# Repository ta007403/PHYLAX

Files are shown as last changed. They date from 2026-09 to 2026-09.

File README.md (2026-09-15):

# PHYLAX — Open-Source Bitcoin Hardware Wallet

**PHX-001 · Version 3 · Square Button**

PHYLAX (Greek *φύλαξ*, "guardian") is an open-source, Bitcoin-only hardware wallet built around a simple idea: no black-box chips, no wireless radios, no telemetry, and firmware you can read and verify yourself. This repository contains the KiCad hardware design files for the PHYLAX Version 3 board (square button variant).

🌐 Website: [phylaxwallet.com](https://phylaxwallet.com/)

> **Status:** In development — prototype targeted for Q4 2026. Hardware and firmware are subject to change.

---

## Why PHYLAX

- **Zero black-box chips** — no proprietary secure element; every component is one you can trace and verify.
- **Fully open firmware** — released under GPL v3.
- **Bitcoin-only** — no altcoins, no unnecessary attack surface.
- **No wireless radios, no telemetry** — the device only talks over USB-C, and only when you plug it in.
- **Built by the community** — the project is developed and audited in the open.

## What's in This Repository

This is a **KiCad 8 project** containing the schematic, PCB layout, 3D models, fabrication outputs, and supporting library parts for the PHYLAX board.

```
Phylax_Version_3 Square Button/
├── Phylax_Version_3.kicad_pro       # KiCad project file
├── Phylax_Version_3.kicad_sch       # Schematic
├── Phylax_Version_3.kicad_pcb       # PCB layout
├── 3D/                              # 3D models & case designs (.step, .stl, .FCStd, .scad)
├── Library/                         # Custom symbol, footprint, and 3D model libraries per part
├── Gerber/                          # Fabrication (Gerber/drill) outputs
├── PCB Outline/                     # Board outline drawings (DXF/PDF)
├── production/                      # BOM, position files, netlist, and production archives
├── Phylax_Version_3-backups/        # KiCad autosave/backup archives
├── fp-lib-table / sym-lib-table     # KiCad footprint & symbol library tables
└── Button Note.txt                  # Working design notes on component substitutions
```

### Key components

| Part | Role |
|---|---|
| STM32F205RET6 | Main microcontroller |
| SX1308 | Boost converter |
| MCP1703AT-3302E | 3.3V LDO regulator |
| USB4215-03-A | USB-C connector |
| SKHCBEA010 | Tactile push button |
| ABMM2-8.000MHZ-E2-T | Crystal oscillator |

*(See `production/bom.csv` for the full bill of materials.)*

## Getting Started

### Prerequisites

- [KiCad 8](https://www.kicad.org/download/) or later
- (Optional) [FreeCAD](https://www.freecad.org/) to view/edit the `.FCStd` case files
- (Optional) [OpenSCAD](https://openscad.org/) to view/edit the `.scad` case files

### Opening the project

1. Clone this repository:
   ```bash
   git clone https://github.com/ta007403/PHYLAX.git
   cd PHYLAX
   ```
2. Open `Phylax_Version_3.kicad_pro` in KiCad.
3. Schematic, PCB, and 3D viewer are all accessible from the KiCad project manager.

### Manufacturing

Fabrication-ready outputs (Gerbers, drill files, BOM, and pick-and-place data) are provided in the `Gerber/` and `production/` folders for sending directly to a PCB manufacturer/assembler.

## Contributing

PHYLAX is built in the open and welcomes community review and contributions — from schematic review to case design. Please open an issue or pull request with proposed changes. If you spot a design or safety issue, responsible disclosure is appreciated.

## License

Firmware and hardware design files are released under **GPL v3** unless otherwise noted. See the [PHYLAX manifesto](https://phylaxwallet.com/manifesto) and [specs](https://phylaxwallet.com/specs) for more on the project's philosophy and technical details.

## Links

- Website: [phylaxwallet.com](https://phylaxwallet.com/)
- Specifications: [phylaxwallet.com/specs](https://phylaxwallet.com/specs)
- Manifesto: [phylaxwallet.com/manifesto](https://phylaxwallet.com/manifesto)
- Journal / build updates: [phylaxwallet.com/journal](https://phylaxwallet.com/journal/)
- Facebook: [facebook.com/phylaxwallet](https://www.facebook.com/phylaxwallet)

---

*Not your keys, not your coins — PHYLAX gives you the keys.*

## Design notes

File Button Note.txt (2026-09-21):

SKHCBEA010 = 1.27 N
SKHCBGA010  =2.55 N

Switch Caps
SK2AA00090 = Black
SK2AA00080 = Ivory
SK2AA00060 = Red
SK2AA00070 = Blue

RC0603FR-07910KL แทด 910k 1% R
RC0603FR-0710KL แทน 10K 1% R

C2827688 ทดแทน PRTR5V0U2X

รอบหน้าต้องแก้
I think the real issue is not the capacitors.
Your design comments indicate:

22 µF / 25 V 1206
4.7 µF / 25 V 0805
10 µF / 16 V 0805

But the PCB footprint is 0603.

------------------------------------------------
LCSC Part #
100nFX7R0603 = C14663
100nFX7R25V0603 = C14663
R1 R2 = C852856
R3 = C313710
R4 = C2686485
R5 = C22356470
R7 = C2909316
R9 = C137672
R10 = C2974031
R11 = C98220

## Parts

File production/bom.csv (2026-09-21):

Designator | Footprint | Quantity | Value | LCSC Part #
C1 | 0603 | 1 | 1nF 200V X7R 0603
C10, C11, C12, C17, C20, C22, C4, C8, C9 | 0603 | 9 | 100nF X7R 25V 0603 | C14663
C13, C14 | 0603 | 2 | 2.2uF X7R 0603
C15 | 0805 | 1 | 4.7uF X7R 25V 0805
C16, C5, C6 | 0603 | 3 | 1uF X7R 0603
C2, C3 | 0402 | 2 | 22pF X7R 0402
C21 | 1206 | 1 | 22uF X5R 25V 1206
C23 | 0805 | 1 | 10uF X7R 16V 0805
C7 | 0603 | 1 | 4.7uF X7R 0603
D1 | PRTR5V0U2X | 1 | PRTR5V0U2X,215 | C12333
D2 | SOD2513X117N | 1 | BAT60JFILM | C133103
D3 | SOD-123_L2.7-W1.6-LS3.7-RD | 1 | 1N5819HW-7-F | C82544
F2 | FUSC4632X85N | 1 | MF-MSMF050-2 | C17313
IC1 | SOT95P255X145-3N | 1 | MCP1703AT-3302E_CB | C144183
IC2 | QFP50P1200X1200X160-64N | 1 | STM32F205RET6 | C66278
J2 | FH19C24S05SH10 | 1 | FH19C-24S-0.5SH_10_ | C6555469
L2 | IND-SMD_L4.0-W4.0_XAL4040 | 1 | XAL4040-103MEC | C5144883
R1, R2 | 0402 | 2 | 5.1k +-1% 0402 | C852856
R10 | 0603 | 1 | 191k +-1% 0603 | C2974031
R11 | 0603 | 1 | 10k +-1% 0603 | C98220
R3 | 0603 | 1 | 22R +-1% 0603 | C313710
R4 | 0402 | 1 | 22R +-1% 0402 | C2686485
R5 | 0603 | 1 | 1M +-1% 0603 | C22356470
R7 | 0402 | 1 | 12k +-1% 0402 | C2909316
R9 | 0603 | 1 | 910k +-1% 0603 | C23263
S1, S3 | SKHCBGA010 | 2 | SKHCBGA010
U1 | SOT-23-6_L2.9-W1.6-P0.95-LS2.8-BL | 1 | SX1308 | C78162
USB1 | USB-C-SMD_GT-USB-7010B | 1 | USB4215-03-A | C37616412
Y1 | ABMM2 | 1 | ABMM2-8.000MHZ-E2-T | C431529

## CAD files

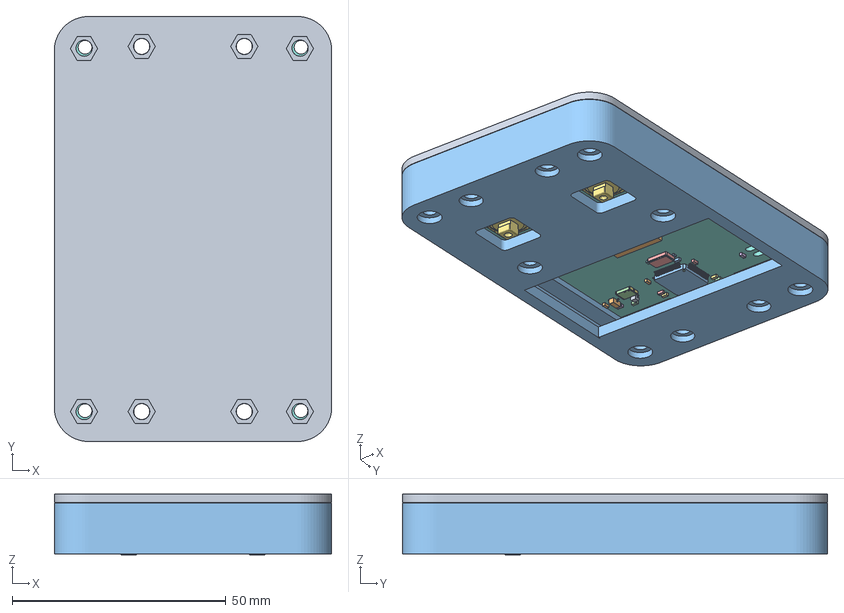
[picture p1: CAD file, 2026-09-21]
3D/Version 3.3/Assembly.FCStd
64.9 x 99.4 x 14.3 mm
C_0603_1608Metric
C_0603_1608Metric001
SOD-123_L2.7-W1.6-H1.4-LS3.7
SDSDS
SDSDS001
pIN eXTEND
pIN eXTEND001
gOLD
gOLD001
gOLD002
gOLD003
Bourns Logo-LAPTOP-NQA1DCQ3
Bourns Logo-LAPTOP-NQA1DCQ001
Bourns Logo-LAPTOP-NQA1DCQ002
Bourns Logo-LAPTOP-NQA1DCQ003
Bourns Logo-LAPTOP-NQA1DCQ004
Bourns Logo-LAPTOP-NQA1DCQ005
C_0402_1005Metric
C_0603_1608Metric002
C_0603_1608Metric003
C_0603_1608Metric004
SKHCBEA010
C_0603_1608Metric005
R_0603_1608Metric
Pins
Pins001
Pins002
Pins003
Pins004
Pins005
Pins006
Pins007
Pins008
Pins009
Pins010
Pins011
Pins012
Pins013
Pins014
Pins015
Pins016
Pins017
Pins018
Pins019
Pins020
Pins021
Pins022
Pins023
Pins024
Pins025
ABMM2-8.000MHZ-E2-T
C_0603_1608Metric006
C_0603_1608Metric007
SOT-23-6_L2.9-W1.6-H1.5-LS2.8-P0.95
SOT-23-6_L2.9-W1.6-H1.5-LS2.8-P0.001
SOT-23-6_L2.9-W1.6-H1.5-LS2.8-P0.002
SOT-23-6_L2.9-W1.6-H1.5-LS2.8-P0.003
SOT-23-6_L2.9-W1.6-H1.5-LS2.8-P0.004
SOT-23-6_L2.9-W1.6-H1.5-LS2.8-P0.005
SOT-23-6_L2.9-W1.6-H1.5-LS2.8-P0.006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

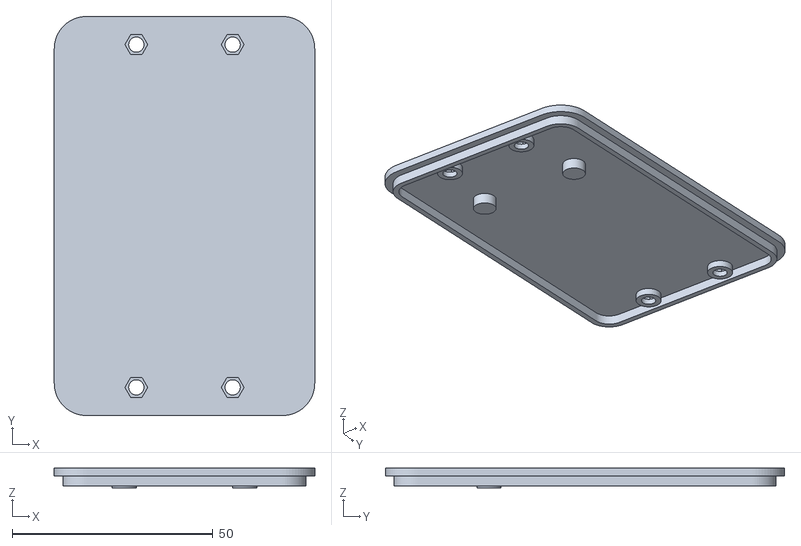
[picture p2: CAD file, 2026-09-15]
3D/Back Tar Version v3.stl
64.9 x 99.4 x 4.90

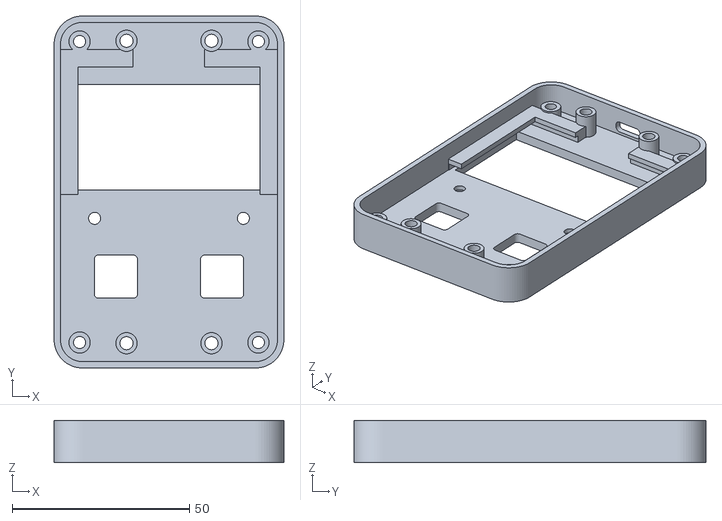
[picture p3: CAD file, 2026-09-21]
3D/Version 3.3/Front v3-3.stl
64.9 x 99.4 x 11.9

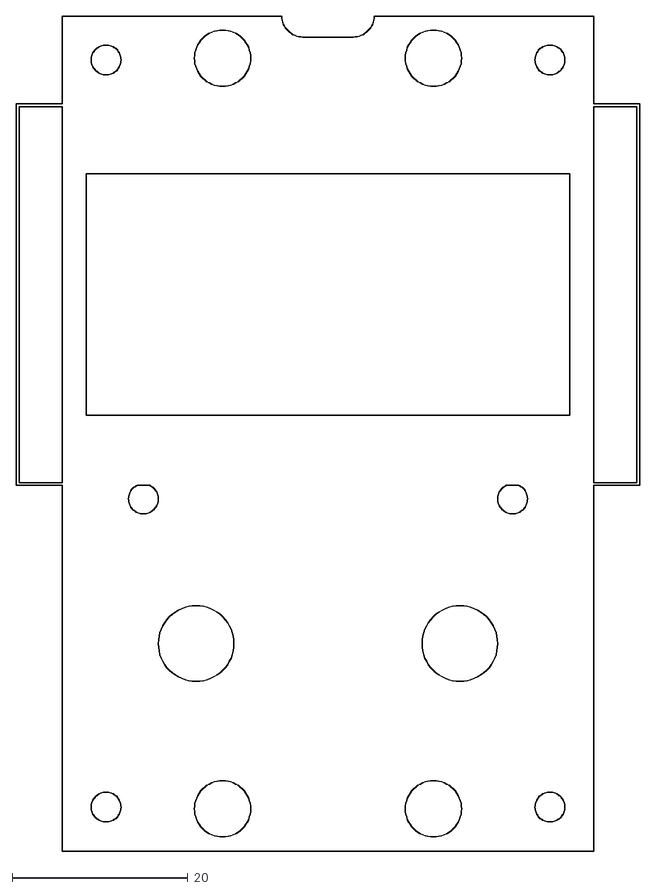
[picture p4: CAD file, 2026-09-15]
PCB Outline/PCB_Outline_Version3.dxf
70.9 x 95.0

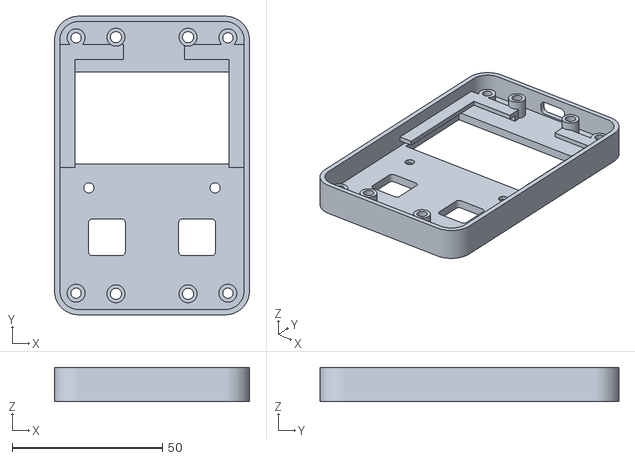
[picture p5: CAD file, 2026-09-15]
3D/Front Tar Version v3.stl
64.9 x 99.4 x 11.4

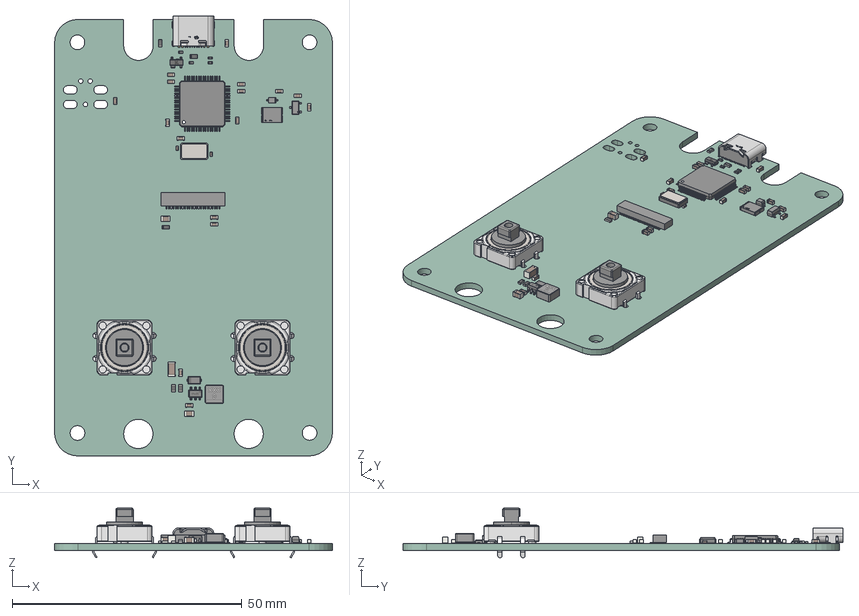
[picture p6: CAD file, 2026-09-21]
3D/Version 3.3/Phylax_Version_3-2.step
60.5 x 95.7 x 10.8 mm
C_0603_1608Metric x 16
SOD-123_L2.7-W1.6-H1.4-LS3.7
SDSDS
pIN eXTEND
gOLD
Bourns Logo-LAPTOP-NQA1DCQ3
C_0402_1005Metric x 2
SKHCBEA010 x 2
R_0603_1608Metric x 5
Pins
ABMM2-8.000MHZ-E2-T
SOT-23-6_L2.9-W1.6-H1.5-LS2.8-P0.95
R_0402_1005Metric x 4
C_1206_3216Metric
PinsArrayL
FilletPinR x 2
C_0805_2012Metric x 2
USB-C-SMD_GT-USB-7010B
FilletPinL
IND-SMD_L4.0-W4.0_XAL4040
STM32F205RET6
SOT143B lower body
SOT143B small Lead x 3
SOT143B Large lead
SOT143B Upper body
Phylax_Version_3_PCB

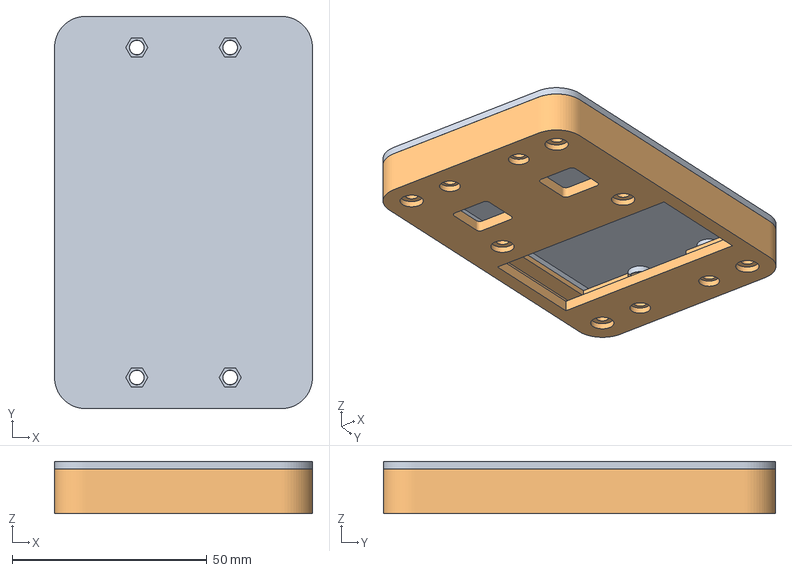
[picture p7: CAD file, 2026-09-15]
3D/Phylax 3D Test v3.FCStd
66.3 x 100.8 x 13.4 mm
Back Tar Version v3
Front Tar Version v3
Front Tar Version v004

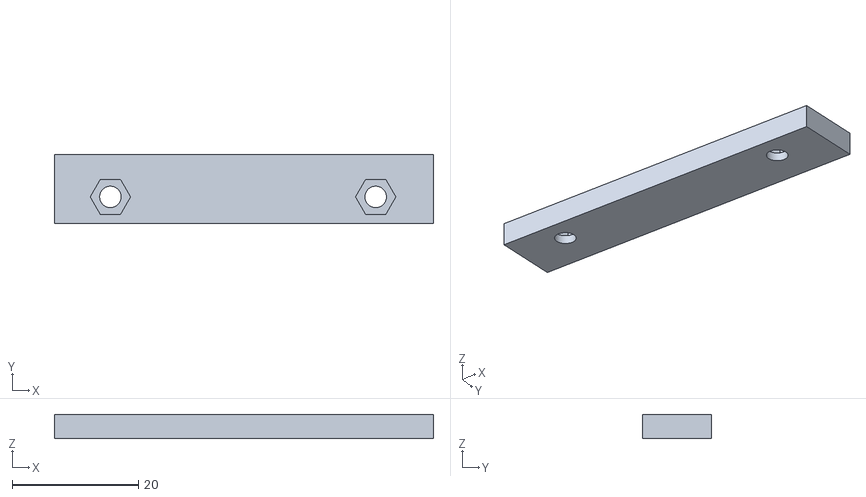
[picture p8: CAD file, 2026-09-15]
3D/Version 3.3/Display Lock v3-2.stl
60.0 x 11.0 x 3.80

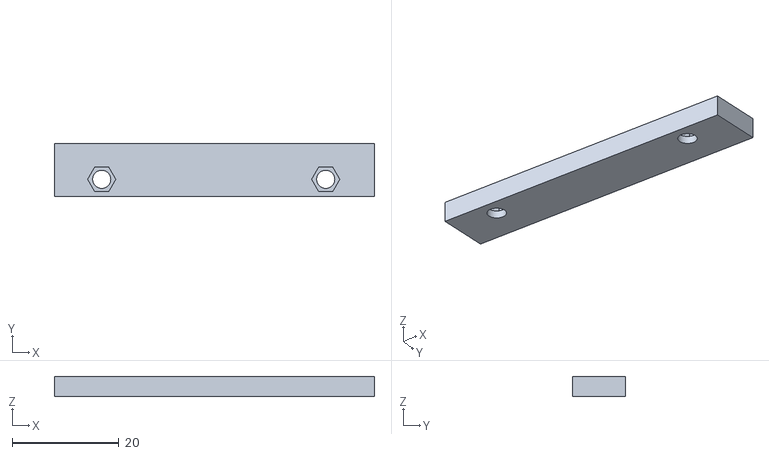
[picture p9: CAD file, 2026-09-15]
3D/Display Lock Tar Version v3.stl
60.0 x 10.0 x 3.80

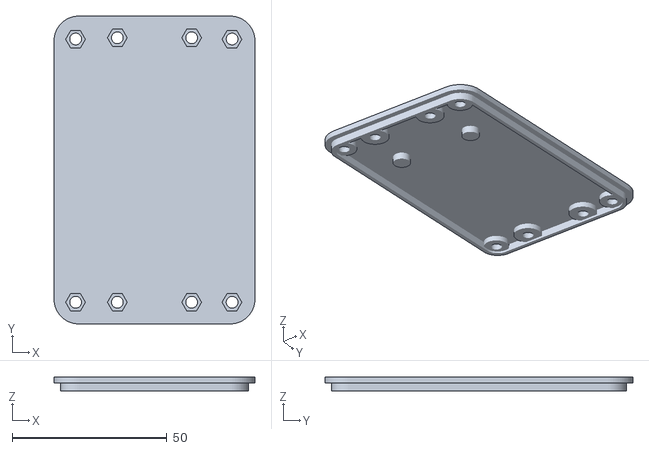
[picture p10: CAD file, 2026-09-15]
3D/Version 3.3/Back v3-3.stl
64.9 x 99.4 x 4.50

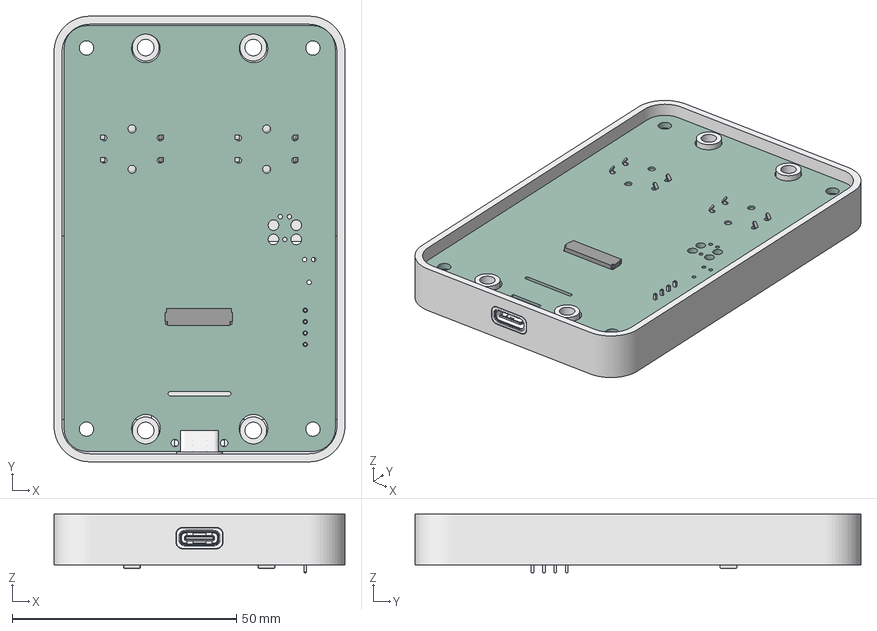
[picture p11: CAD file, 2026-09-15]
3D/PCB + Front.FCStd
64.9 x 99.4 x 13.1 mm
C_0603_1608Metric
C_0603_1608Metric001
C_0402_1005Metric
C_0603_1608Metric002
C_0603_1608Metric003
C_0603_1608Metric004
SKHCBEA010
C_0603_1608Metric005
R_0603_1608Metric
ABMM2-8.000MHZ-E2-T
C_0603_1608Metric006
C_0603_1608Metric007
R_0603_1608Metric001
10178589-00011LF
R_0603_1608Metric002
R_0603_1608Metric003
PinsArrayL
PinsArrayL001
FilletPinR
term1
term2
C_0603_1608Metric008
C_0603_1608Metric009
R_0603_1608Metric004
C_0603_1608Metric010
R_0603_1608Metric005
R_0603_1608Metric006
FilletPinL
FilletPinR001
R_0603_1608Metric007
C_0603_1608Metric011
SKHCBEA011
C_0402_1005Metric001
C_0603_1608Metric012
C_0603_1608Metric013
C_0603_1608Metric014
R_0603_1608Metric008
STM32F205RET6
STM32F205RET007
STM32F205RET008
STM32F205RET009
STM32F205RET010
STM32F205RET011
STM32F205RET012
STM32F205RET013
STM32F205RET014
STM32F205RET015
STM32F205RET016
STM32F205RET017
STM32F205RET018
STM32F205RET019
STM32F205RET020
STM32F205RET021
STM32F205RET022
STM32F205RET023
STM32F205RET024
STM32F205RET025
STM32F205RET026
STM32F205RET027
STM32F205RET028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

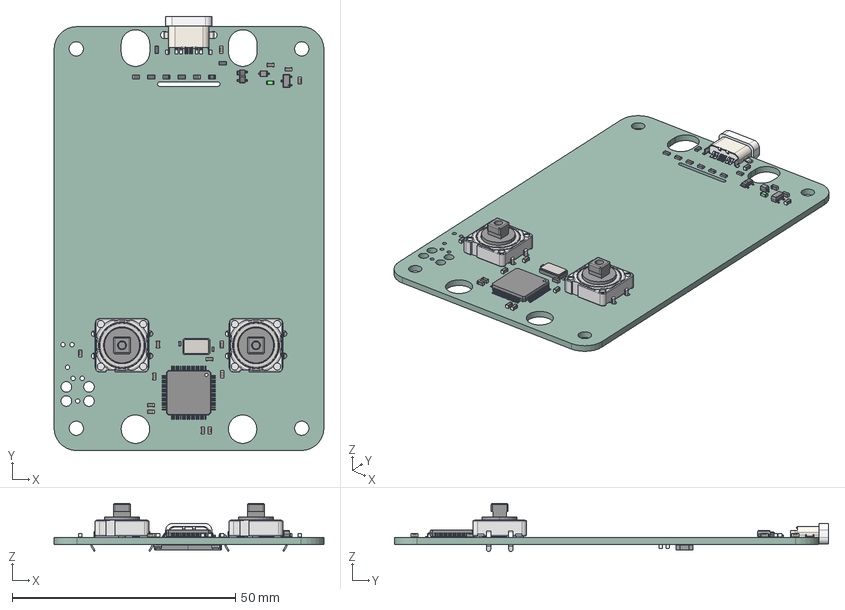
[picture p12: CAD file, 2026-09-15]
3D/Phylax_Version_3.step
60.5 x 97.3 x 10.8 mm
C_0603_1608Metric x 17
C_0402_1005Metric x 2
SKHCBEA010 x 2
R_0603_1608Metric x 9
ABMM2-8.000MHZ-E2-T
10178589-00011LF
PinsArrayL
FilletPinR x 2
term1
term2
FilletPinL
STM32F205RET6
SOT143B lower body
SOT143B small Lead x 3
SOT143B Large lead
SOT143B Upper body
Pins
Phylax_Version_3_PCB

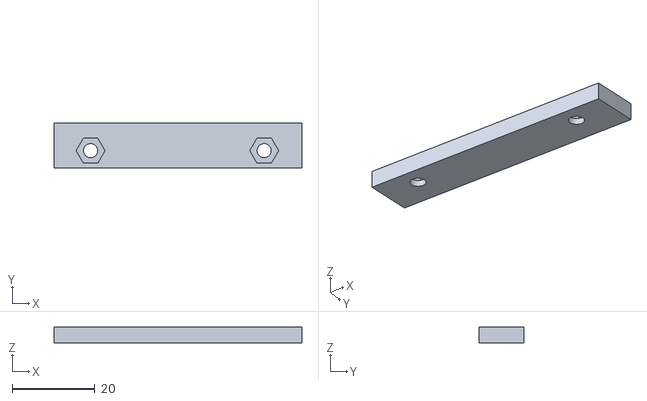
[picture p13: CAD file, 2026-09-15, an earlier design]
3D/Version 3.1/Display Lock v3-1.stl
60.0 x 11.0 x 3.80

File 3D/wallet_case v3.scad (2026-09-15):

// ============================================================
// HARDWARE WALLET CASE — Parametric OpenSCAD
// 2.42" SSD1309 OLED + 2x E-Switch TL1105YF160Q tact switches + USB-C
// PCB: 75 x 120 x 1.6mm
// ============================================================
//
// HOW TO USE THIS FILE
// ---------------------------------------------------------------
// Open the CUSTOMIZER panel: Window menu > Customizer (or the icon that
// looks like a slider/wrench in the toolbar). You'll see grouped controls:
//   - "View / Render Mode"     <- pick which part to look at / export
//   - "PCB", "Display", "Buttons", "USB-C Connector", "PCB Mounting Screws"
//   - "Case Shell", "Screw Bosses", "Front Shell Lip"
//
// To switch parts: open "View / Render Mode" and change the render_mode
// dropdown to back_shell / front_shell / button_cap / assembly.
//
// To print: pick a part in render_mode (NOT "assembly", that's preview-only),
// then File > Export > Export as STL. Repeat for each of the 3 parts
// (back_shell, front_shell, button_cap -- button_cap exports both caps
// laid out side by side in one file).
//
// Any value you change in the Customizer updates the model live. If you'd
// rather edit numbers directly in code, the same variables are declared in
// SECTION 1 / 1b below (search for the variable name) -- Customizer and
// direct code editing both work on the same values.
//
// PRINTING NOTES
// ---------------------------------------------------------------
// - Two shells (back_shell, front_shell) + two button_cap copies = 4 prints total.
// - Tolerances below are tuned for FDM with a 0.4mm nozzle. If you switch
//   to resin/SLA, look for "Front Shell Lip" group and tighten lip_clearance.
// - Back shell: print with the open face UP (no supports needed for the
//   bosses, since they're vertical cylinders rising from a flat floor).
// - Front shell: print with the BUTTON/DISPLAY face DOWN on the bed, since
//   the registration lip on the back is just a thin wall (prints fine
//   either way, but face-down avoids any visible seam on the visible side).
// - Button caps: print either orientation; they're small and simple.
//
// ============================================================

// Render quality
$fn = 64;

// I have modify this section
hex_round_head_m3_high = 1.65;
hide_m3_head = 4 - hex_round_head_m3_high;

/* [View / Render Mode] */
// Which part to show. Pick one, then File > Export > STL to print it.
render_mode = "assembly"; // [assembly:Assembly (preview only), back_shell:Back Shell (print 1x), front_shell:Front Shell (print 1x), button_cap:Button Caps (print 2x), display_lock:Display Lock (print 1x),front_and_lock:Front Shell + Display Lock, pcb_outline:PCB Outline (export as DXF for KiCad), none:Nothing]

/* [PCB] */
pcb_length   = 95;   // [60:200] mm, long axis (Y)
pcb_width    = 60.5;    // [40:150] mm, short axis (X)
pcb_thick    = 1.6;   // [0.8:0.1:3.2] mm

/* [Display - 2.42" SSD1309] */
disp_mod_w     = 70.9;   // mm, module long edge (runs along PCB width/X)
disp_mod_h     = 43.4;   // mm, module short edge (runs along PCB length/Y)
disp_active_w  = 55.01;  // mm, active viewing area width
disp_active_h  = 27.49;  // mm, active viewing area height
disp_pcb_thick = 1.2;    // mm, OLED module PCB thickness (assumption, thin FR4)
disp_glass_standoff = 0.5; // mm, assumption: glass sits slightly proud of module PCB
disp_margin_top = 10;     // [0:20] mm, gap from top edge of PCB to top edge of display module
disp_window_margin = 1.5; // [0.5:0.1:4] mm, extra margin around active area for the front cutout

/* [Buttons - Same Sky TS15-1212 Series] */
btn_body        = 12.0;   // mm, switch body (12x12mm per TS15 datasheet)
btn_plunger_d   = 7.0;    // mm, round actuator diameter (per TS15 mechanical drawing)
btn_plunger_h   = 4.8;   // [5:0.5:15] mm, actuator height above PCB -- set to match
                           // your ordered variant: 100=10mm, 150=15mm, 200=20mm (wrong series -- TS15 max is 15mm)
btn_spacing     = 30;     // [15:80] mm, center-to-center distance between the two buttons
btn_offset_below_display = 18; // [5:50] mm, gap from bottom of display to button row
btn_travel_above_case = 1.8; // [0.5:0.1:4] mm, how far the button DOME pokes above the front
                              // face -- this is what controls "how proud/clicky" the button
                              // looks and feels. Independent of plunger height: the shaft
                              // length to reach the plunger is calculated automatically.

/* [USB-C Connector] */
// Pick your connector type — all dimensions auto-adjust.
usbc_type = "normal"; // [sink:Sink Type - Amphenol 10178589 (IPX5 waterproof), normal:Normal SMD USB-C (standard)]

// Clearance added around the oval cutout on ALL sides.
// 0.4mm = safe FDM starting point. Decrease if plug is loose, increase if too tight.
usbc_clearance = 0.0; // [0.1:0.05:1.0] mm

/* [FPC Display Connector - Molex 522072460] */
// 24-circuit, 1mm pitch, right-angle SMD, 2.70mm height
// Place this connector so the FPC ribbon exits toward the display module above it.
fpc_w           = 26.0;  // mm, connector body width (24 circuits × 1mm pitch + housing ends ~2mm)
fpc_d           = 5.5;   // mm, connector body depth (right-angle footprint)
fpc_h           = 2.7;   // mm, connector height above PCB (from datasheet: 2.70mm)
// Position: centered on X, placed in the top half of PCB near the display edge
fpc_offset_from_top = 8; // [2:30] mm, distance from top PCB edge to near edge of connector


/* [PCB Mounting Screws - M3 + Nut] */
// PCB now mounts to the FRONT shell (display side), not the back shell.
// Screw enters from the OUTSIDE of the front shell (visible head, countersunk),
// passes through the PCB, and threads into a hex nut trapped inside the front
// shell's cavity wall. This lets the PCB stay attached to the front shell when
// the case is opened -- keeping the display's short FPC cable untouched.
mount_inset      = 5;    // [5:20] mm, distance of each screw position from PCB edge.
                           // Must clear BOTH the rounded case corners AND the
                           // display window edges -- 17mm verified clear of both
                           // with margin (M3 boss is 5mm dia). If you change
                           // disp_window size, case_corner_r, or pcb_boss_od,
                           // re-check this.
mount_hole_d     = 3.4;   // [3.0:0.1:4.0] mm, PCB clearance hole for M3 screw shank
m3_screw_d       = 3.0;   // mm, M3 screw nominal diameter (reference only)
m3_clear_d       = 3.4;   // [3.2:0.1:4.0] mm, clearance hole through front shell wall + PCB
m3_head_d        = 6.0;   // [5.5:0.1:7.0] mm, M3 COUNTERSUNK (flat head) screw head
                           // diameter -- DIN 965/ISO 7046 spec, e.g. M3x8 has 6.0mm head.
                           // Use a countersunk screw (not cap/pan head) so it sits flush.
m3_head_h        = 1.7;   // [1.5:0.1:2.5] mm, M3 countersunk head height (DIN 965 spec) --
                           // much shallower than a cap/pan head, fits cleanly within
                           // front_panel_t without needing a backing pad.
m3_nut_af        = 5.5;   // [5.3:0.1:6.0] mm, M3 hex nut width across flats
m3_nut_h         = 2.4;   // [2.0:0.1:3.0] mm, M3 hex nut thickness
m3_nut_clearance = 0.2;   // [0.05:0.05:0.4] mm, extra clearance around nut so it slides into the trap

/* [Display Lock Screws - M3 + Nut] */
// Two small M3 screws below the display window, used to hold a separate
// printed retainer piece that clamps the display's BOTTOM edge once it has
// been slid into the 3-sided L-channel (top/left/right) molded into the
// front shell. Positions are tied to the display window, not hardcoded,
// so they follow disp_center_x/y automatically if the display moves.
disp_lock_inset_x  = 8;    // [2:20] mm, how far in from each window side-edge
disp_lock_offset_y = 8;    // [2:20] mm, gap below the window's bottom edge
disp_lock_boss_od  = 5.0;  // [3:0.5:8] mm, lock screw boss outer diameter
                            // (smaller than the main PCB bosses -- this only
                            // holds a thin retainer clip, not the whole PCB)

/* [Hidden] */
disp_center_x   = pcb_width/2;
disp_center_y   = pcb_length - disp_margin_top - disp_mod_h/2;
usbc_center_x = pcb_width/2;
btn_center_y    = disp_center_y - disp_mod_h/2 - btn_offset_below_display;
btn_center_x_L  = pcb_width/2 - btn_spacing/2;
btn_center_x_R  = pcb_width/2 + btn_spacing/2;

mount_positions = [
    [mount_inset, mount_inset],
    [pcb_width - mount_inset, mount_inset],
    [mount_inset, pcb_length - mount_inset],
    [pcb_width - mount_inset, pcb_length - mount_inset]
];
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

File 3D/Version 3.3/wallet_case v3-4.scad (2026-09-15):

// ============================================================
// HARDWARE WALLET CASE — Parametric OpenSCAD
// 2.42" SSD1309 OLED + 2x E-Switch TL1105YF160Q tact switches + USB-C
// PCB: 75 x 120 x 1.6mm
// ============================================================
//
// HOW TO USE THIS FILE
// ---------------------------------------------------------------
// Open the CUSTOMIZER panel: Window menu > Customizer (or the icon that
// looks like a slider/wrench in the toolbar). You'll see grouped controls:
//   - "View / Render Mode"     <- pick which part to look at / export
//   - "PCB", "Display", "Buttons", "USB-C Connector", "PCB Mounting Screws"
//   - "Case Shell", "Screw Bosses", "Front Shell Lip"
//
// To switch parts: open "View / Render Mode" and change the render_mode
// dropdown to back_shell / front_shell / button_cap / assembly.
//
// To print: pick a part in render_mode (NOT "assembly", that's preview-only),
// then File > Export > Export as STL. Repeat for each of the 3 parts
// (back_shell, front_shell, button_cap -- button_cap exports both caps
// laid out side by side in one file).
//
// Any value you change in the Customizer updates the model live. If you'd
// rather edit numbers directly in code, the same variables are declared in
// SECTION 1 / 1b below (search for the variable name) -- Customizer and
// direct code editing both work on the same values.
//
// PRINTING NOTES
// ---------------------------------------------------------------
// - Two shells (back_shell, front_shell) + two button_cap copies = 4 prints total.
// - Tolerances below are tuned for FDM with a 0.4mm nozzle. If you switch
//   to resin/SLA, look for "Front Shell Lip" group and tighten lip_clearance.
// - Back shell: print with the open face UP (no supports needed for the
//   bosses, since they're vertical cylinders rising from a flat floor).
// - Front shell: print with the BUTTON/DISPLAY face DOWN on the bed, since
//   the registration lip on the back is just a thin wall (prints fine
//   either way, but face-down avoids any visible seam on the visible side).
// - Button caps: print either orientation; they're small and simple.
//
// ============================================================

// Render quality
$fn = 64;

// I have modify this section
hex_round_head_m3_high = 1.65;
hide_m3_head = 4 - hex_round_head_m3_high;

/* [View / Render Mode] */
// Which part to show. Pick one, then File > Export > STL to print it.
render_mode = "assembly"; // [assembly:Assembly (preview only), back_shell:Back Shell (print 1x), front_shell:Front Shell (print 1x), button_cap:Button Caps (print 2x), display_lock:Display Lock (print 1x),front_and_lock:Front Shell + Display Lock, pcb_outline:PCB Outline (export as DXF for KiCad), none:Nothing]

/* [PCB] */
pcb_length   = 95;   // [60:200] mm, long axis (Y)
pcb_width    = 60.5;    // [40:150] mm, short axis (X)
pcb_thick    = 1.6;   // [0.8:0.1:3.2] mm

/* [Display - 2.42" SSD1309] */
disp_mod_w     = 70.9;   // mm, module long edge (runs along PCB width/X)
disp_mod_h     = 43.4;   // mm, module short edge (runs along PCB length/Y)
disp_active_w  = 55.01;  // mm, active viewing area width
disp_active_h  = 27.49;  // mm, active viewing area height
disp_pcb_thick = 1.2;    // mm, OLED module PCB thickness (assumption, thin FR4)
disp_glass_standoff = 0.5; // mm, assumption: glass sits slightly proud of module PCB
disp_margin_top = 10;     // [0:20] mm, gap from top edge of PCB to top edge of display module
disp_window_margin = 1.5; // [0.5:0.1:4] mm, extra margin around active area for the front cutout

/* [Buttons - Same Sky TS15-1212 Series] */
btn_body        = 12.0;   // mm, switch body (12x12mm per TS15 datasheet)
btn_plunger_d   = 7.0;    // mm, round actuator diameter (per TS15 mechanical drawing)
btn_plunger_h   = 4.8;   // [5:0.5:15] mm, actuator height above PCB -- set to match
                           // your ordered variant: 100=10mm, 150=15mm, 200=20mm (wrong series -- TS15 max is 15mm)
btn_spacing     = 30;     // [15:80] mm, center-to-center distance between the two buttons
btn_offset_below_display = 18; // [5:50] mm, gap from bottom of display to button row
btn_travel_above_case = 1.8; // [0.5:0.1:4] mm, how far the button DOME pokes above the front
                              // face -- this is what controls "how proud/clicky" the button
                              // looks and feels. Independent of plunger height: the shaft
                              // length to reach the plunger is calculated automatically.

/* [USB-C Connector] */
// Pick your connector type — all dimensions auto-adjust.
usbc_type = "normal"; // [sink:Sink Type - Amphenol 10178589 (IPX5 waterproof), normal:Normal SMD USB-C (standard)]

// Clearance added around the oval cutout on ALL sides.
// 0.4mm = safe FDM starting point. Decrease if plug is loose, increase if too tight.
usbc_clearance = 0.0; // [0.1:0.05:1.0] mm

/* [FPC Display Connector - Molex 522072460] */
// 24-circuit, 1mm pitch, right-angle SMD, 2.70mm height
// Place this connector so the FPC ribbon exits toward the display module above it.
fpc_w           = 26.0;  // mm, connector body width (24 circuits × 1mm pitch + housing ends ~2mm)
fpc_d           = 5.5;   // mm, connector body depth (right-angle footprint)
fpc_h           = 2.7;   // mm, connector height above PCB (from datasheet: 2.70mm)
// Position: centered on X, placed in the top half of PCB near the display edge
fpc_offset_from_top = 8; // [2:30] mm, distance from top PCB edge to near edge of connector


/* [PCB Mounting Screws - M3 + Nut] */
// PCB now mounts to the FRONT shell (display side), not the back shell.
// Screw enters from the OUTSIDE of the front shell (visible head, countersunk),
// passes through the PCB, and threads into a hex nut trapped inside the front
// shell's cavity wall. This lets the PCB stay attached to the front shell when
// the case is opened -- keeping the display's short FPC cable untouched.
mount_inset      = 5;    // [5:20] mm, distance of each screw position from PCB edge.
                           // Must clear BOTH the rounded case corners AND the
                           // display window edges -- 17mm verified clear of both
                           // with margin (M3 boss is 5mm dia). If you change
                           // disp_window size, case_corner_r, or pcb_boss_od,
                           // re-check this.
mount_hole_d     = 3.4;   // [3.0:0.1:4.0] mm, PCB clearance hole for M3 screw shank
m3_screw_d       = 3.0;   // mm, M3 screw nominal diameter (reference only)
m3_clear_d       = 3.4;   // [3.2:0.1:4.0] mm, clearance hole through front shell wall + PCB

// This one is for outer lock at 4 corner by Tar
m3_head_d        = 5.8;   // [5.5:0.1:7.0] mm, M3 COUNTERSUNK (flat head) screw head
                           // diameter -- DIN 965/ISO 7046 spec, e.g. M3x8 has 6.0mm head.
                           // Use a countersunk screw (not cap/pan head) so it sits flush.
m3_head_h        = 1.7;   // [1.5:0.1:2.5] mm, M3 countersunk head height (DIN 965 spec) --
                           // much shallower than a cap/pan head, fits cleanly within
                           // front_panel_t without needing a backing pad.
m3_nut_af        = 5.5;   // [5.3:0.1:6.0] mm, M3 hex nut width across flats
m3_nut_h         = 2.4;   // [2.0:0.1:3.0] mm, M3 hex nut thickness
m3_nut_clearance = 0.2;   // [0.05:0.05:0.4] mm, extra clearance around nut so it slides into the trap

/* [Display Lock Screws - M3 + Nut] */
// Two small M3 screws below the display window, used to hold a separate
// printed retainer piece that clamps the display's BOTTOM edge once it has
// been slid into the 3-sided L-channel (top/left/right) molded into the
// front shell. Positions are tied to the display window, not hardcoded,
// so they follow disp_center_x/y automatically if the display moves.
disp_lock_inset_x  = 8;    // [2:20] mm, how far in from each window side-edge
disp_lock_offset_y = 8;    // [2:20] mm, gap below the window's bottom edge
disp_lock_boss_od  = 5.0;  // [3:0.5:8] mm, lock screw boss outer diameter
                            // (smaller than the main PCB bosses -- this only
                            // holds a thin retainer clip, not the whole PCB)

/* [Hidden] */
disp_center_x   = pcb_width/2;
disp_center_y   = pcb_length - disp_margin_top - disp_mod_h/2;
usbc_center_x = pcb_width/2;
btn_center_y    = disp_center_y - disp_mod_h/2 - btn_offset_below_display;
btn_center_x_L  = pcb_width/2 - btn_spacing/2;
btn_center_x_R  = pcb_width/2 + btn_spacing/2;

mount_positions = [
    [mount_inset, mount_inset],
    [pcb_width - mount_inset, mount_inset],
    [mount_inset, pcb_length - mount_inset],
    [pcb_width - mount_inset, pcb_length - mount_inset]
];
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

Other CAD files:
3D/Compose.FCStd
3D/Version 3.1/Assembly.FCStd
3D/Version 3.2/Assembly.FCStd
3D/Version 3.2/Phylax_Version_3-1.step
3D/Version 3.1/Front v3-1.stl
3D/Version 3.2/wallet_case v3-3.scad
3D/Version 3.1/Back v3-1.stl
3D/Version 3.1/Back v3-2.stl
3D/Version 3.1/Phylax_Version_3-1.step
3D/Version 3.2/Back v3-1.stl
3D/Version 3.2/Back v3-2.stl
3D/Version 3.2/Front v3-1.stl
3D/Version 3.2/Front v3-2.stl

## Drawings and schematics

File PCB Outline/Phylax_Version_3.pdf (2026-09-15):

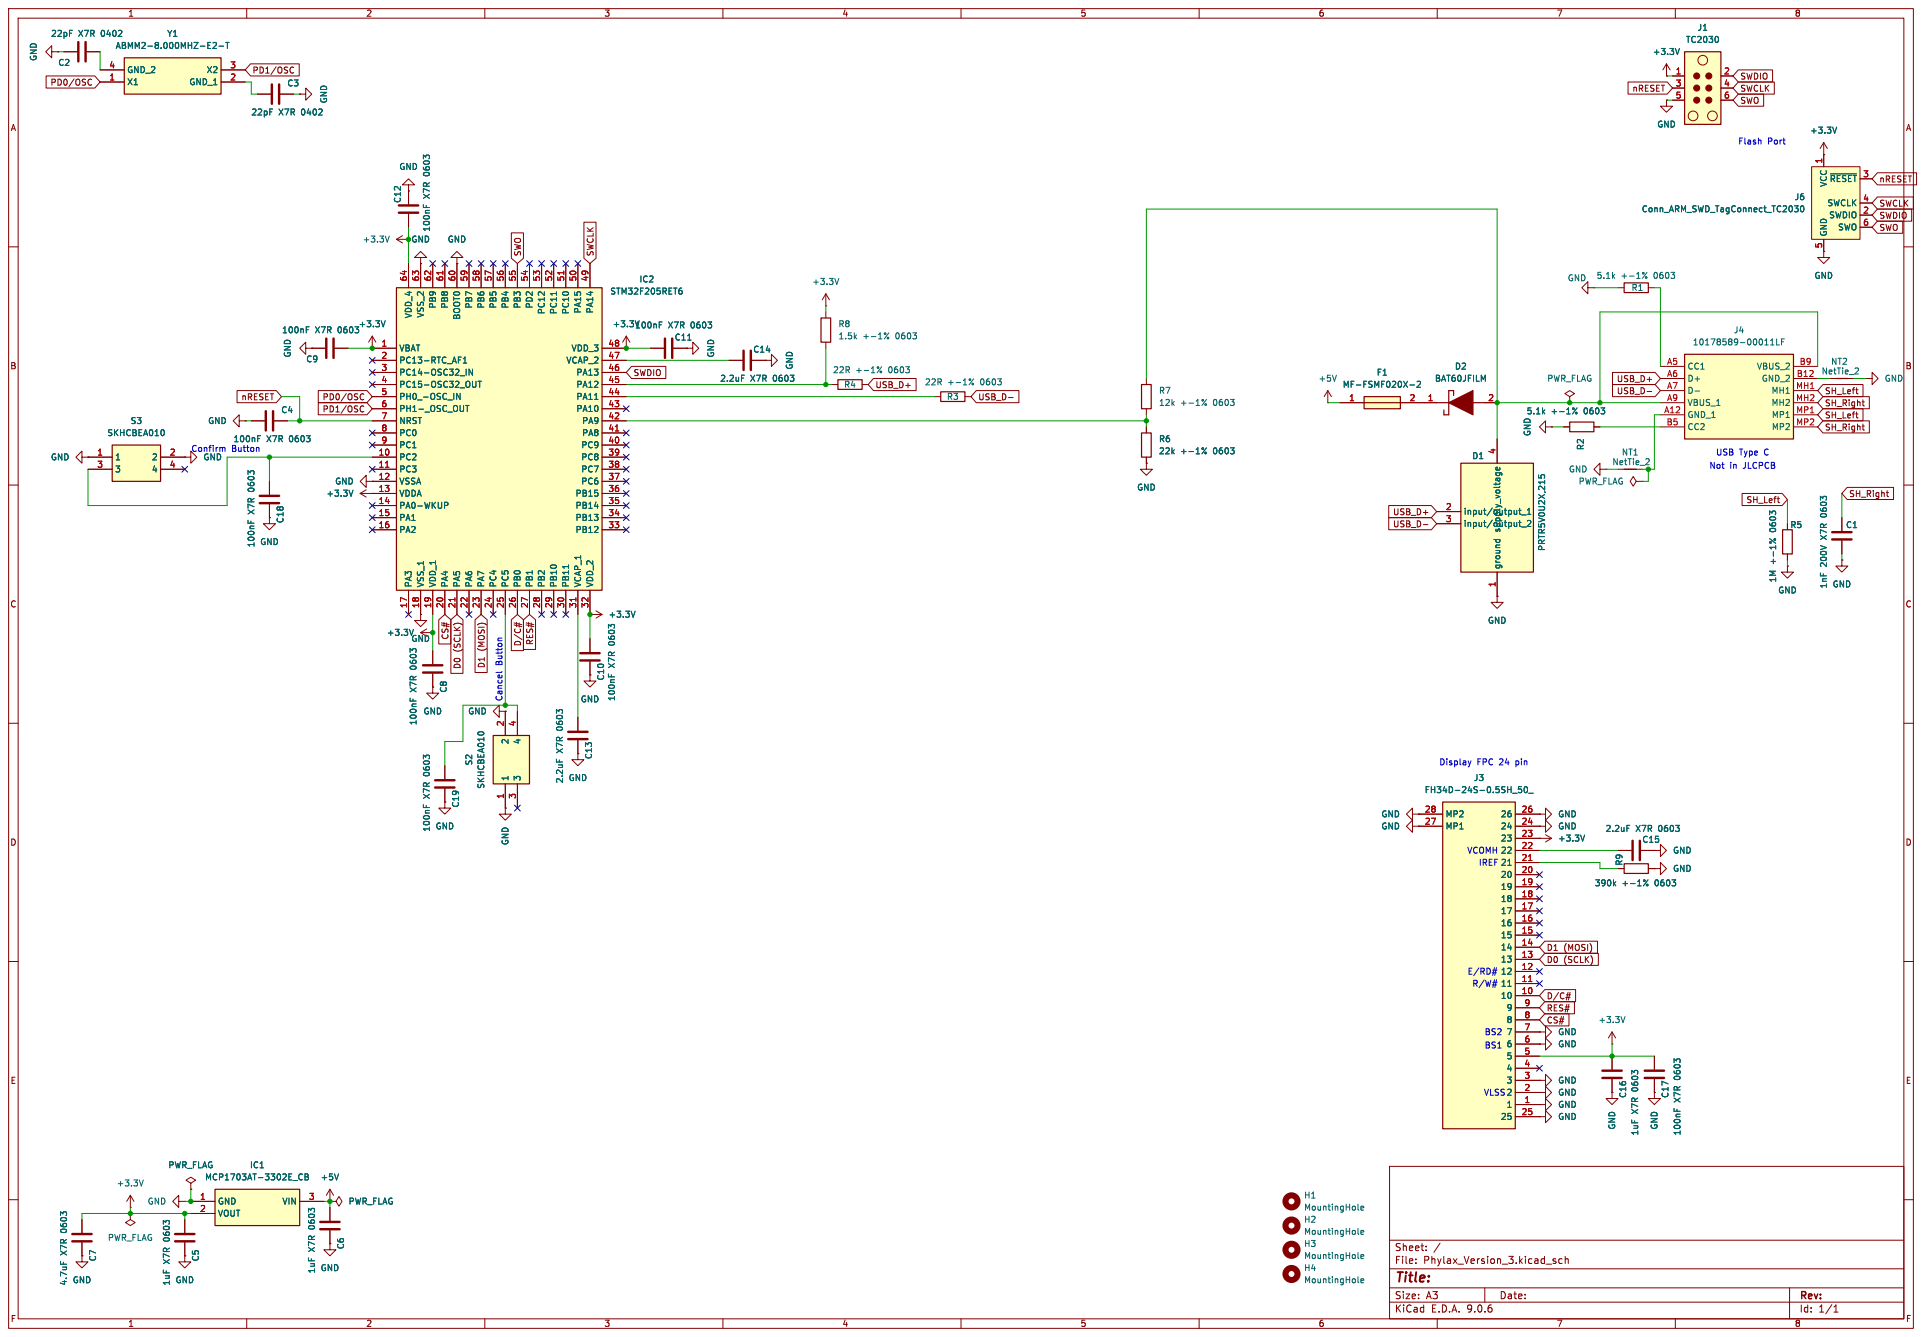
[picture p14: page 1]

4 C18 100nF X7R 0603 GND GND C13 2.2uF X7R 0603 GND C8 100nF X7R 0603 GND

2.2uF X7R 0603GND GND GND GND GND
VLSS R/W# E/RD# VCOMH

H1 MountingHole H2 MountingHole H3 MountingHole H4 MountingHole

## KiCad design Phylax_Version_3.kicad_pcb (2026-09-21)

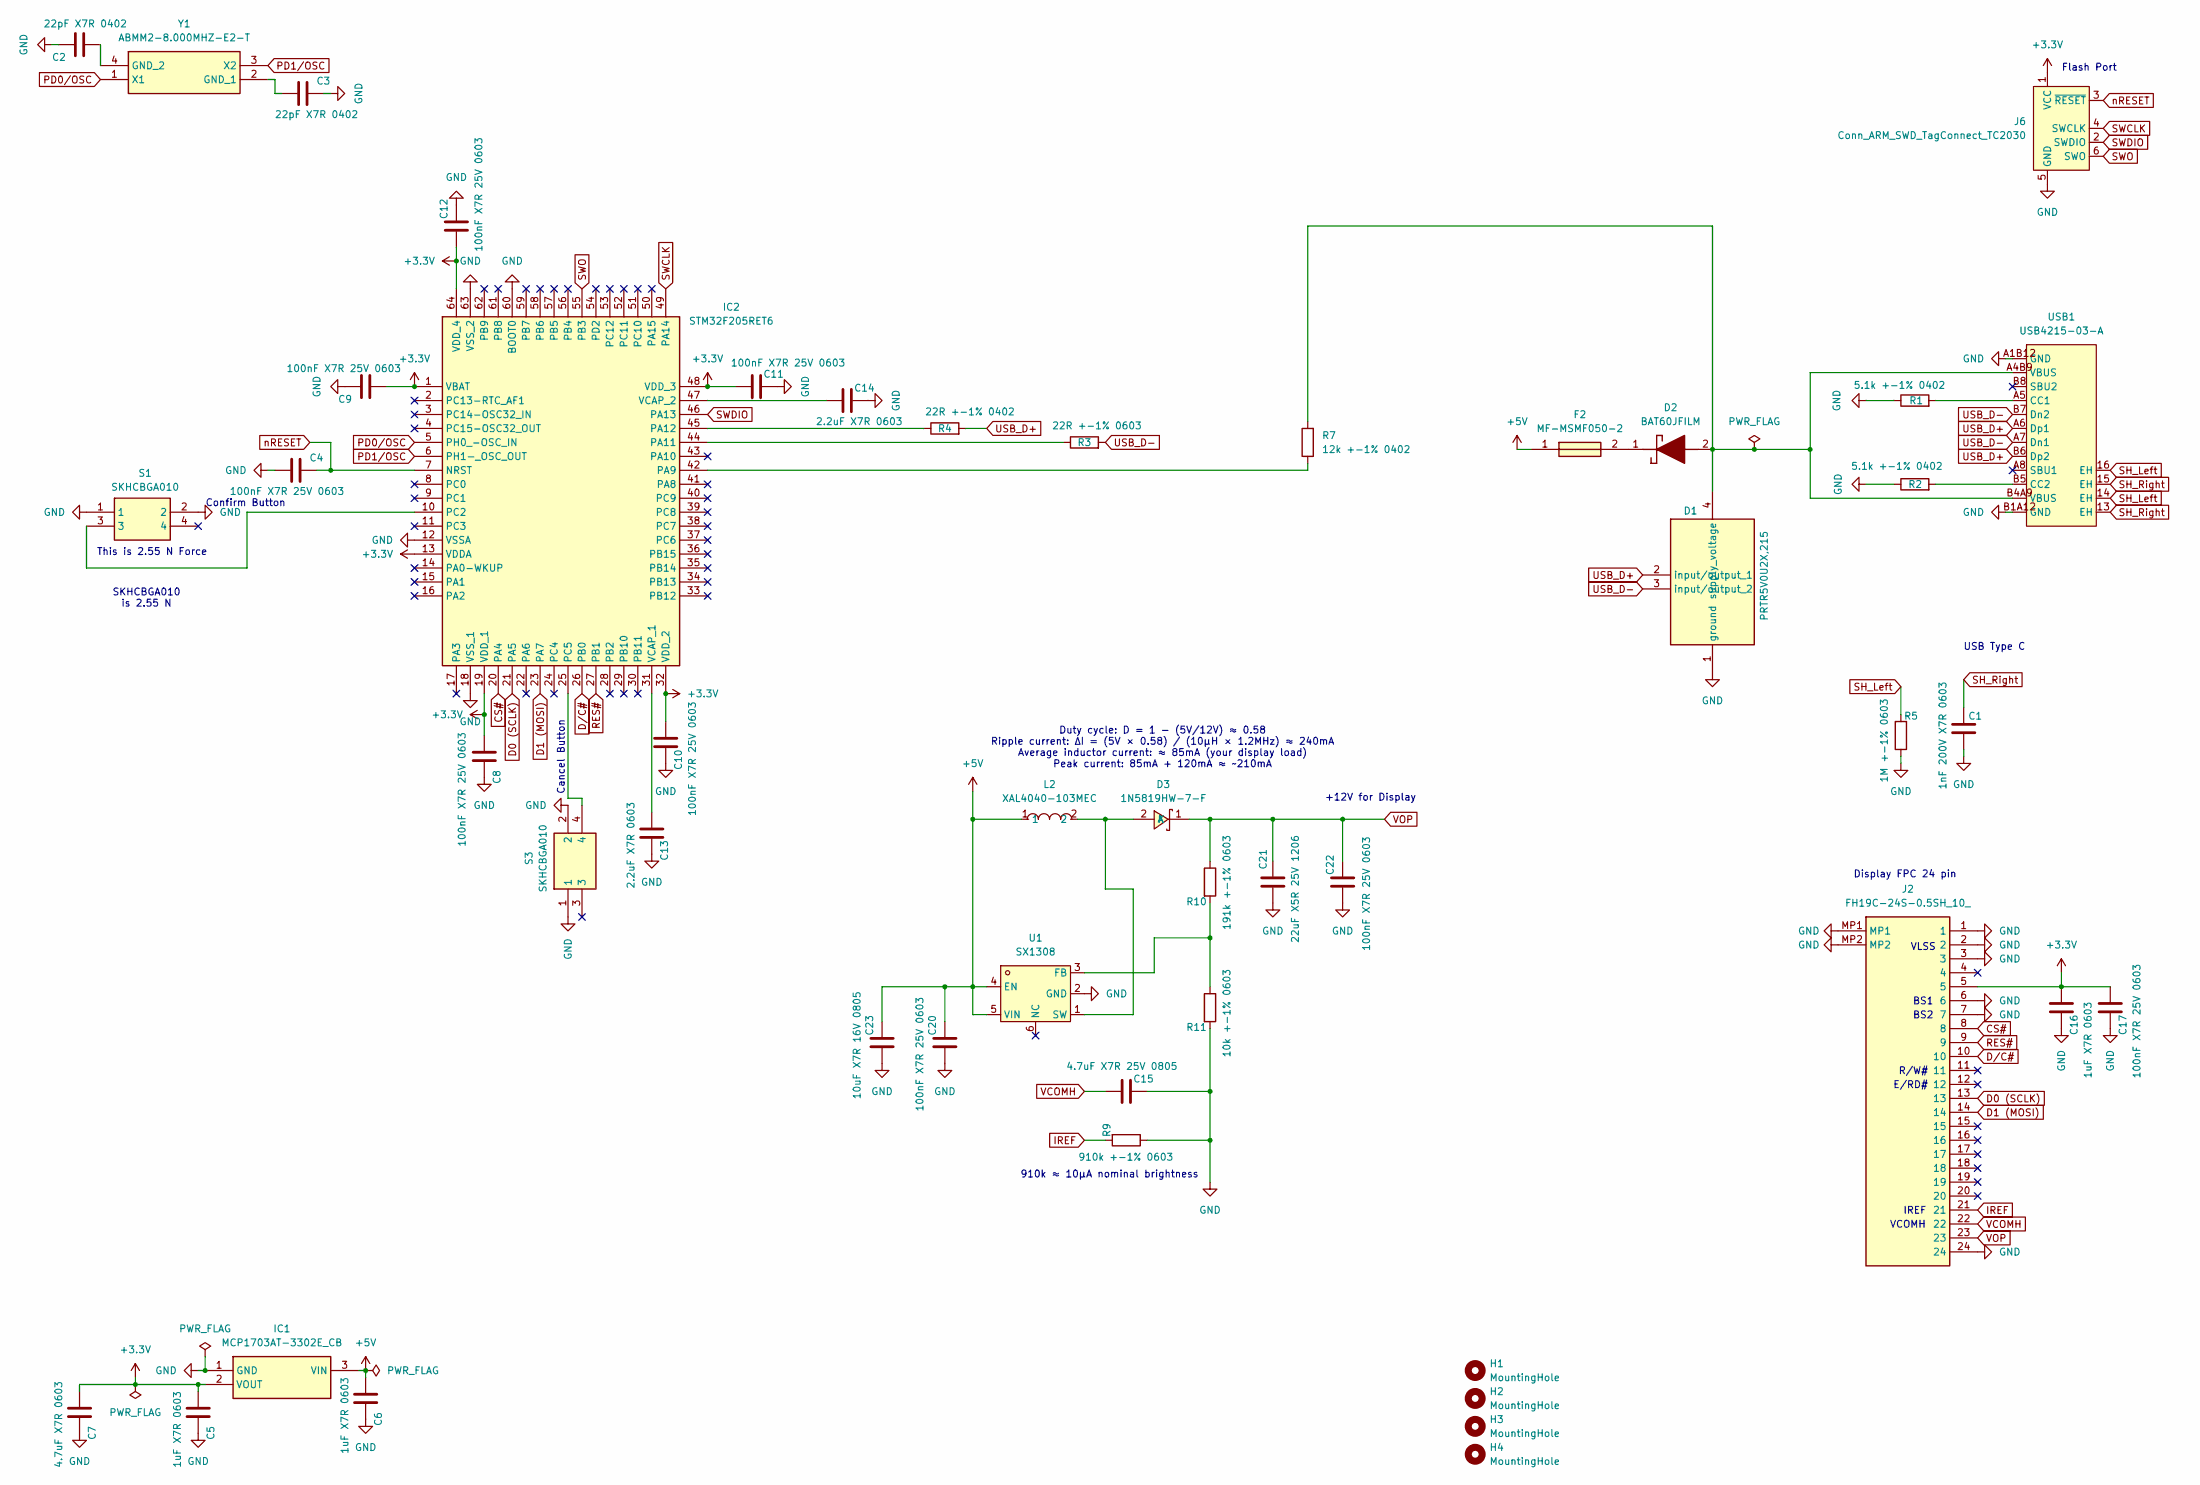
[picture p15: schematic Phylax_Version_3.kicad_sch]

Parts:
C1: 1nF 200V X7R 0603; C_0603_1608Metric_Pad1.08x0.95mm_HandSolder
C2, C3: 22pF X7R 0402; C_0402_1005Metric_Pad0.74x0.62mm_HandSolder
C4, C8, C9, C10, C11, C12, C17, C20, C22: 100nF X7R 25V 0603; C_0603_1608Metric_Pad1.08x0.95mm_HandSolder; LCSC Part # C14663
C5, C6, C16: 1uF X7R 0603; C_0603_1608Metric_Pad1.08x0.95mm_HandSolder
C7: 4.7uF X7R 0603; C_0603_1608Metric_Pad1.08x0.95mm_HandSolder
C13, C14: 2.2uF X7R 0603; C_0603_1608Metric_Pad1.08x0.95mm_HandSolder
C15: 4.7uF X7R 25V 0805; C_0805_2012Metric_Pad1.18x1.45mm_HandSolder
C21: 22uF X5R 25V 1206; C_1206_3216Metric_Pad1.33x1.80mm_HandSolder
C23: 10uF X7R 16V 0805; C_0805_2012Metric_Pad1.18x1.45mm_HandSolder
D1: PRTR5V0U2X,215; PRTR5V0U2X; Mouser Part Number 771-PRTR5V0U2X-T/R
D2: BAT60JFILM; SOD2513X117N; Mouser Part Number 511-BAT60JFILM
D3: 1N5819HW-7-F; SOD-123_L2.7-W1.6-LS3.7-RD; MPN 1N5819HW-7-F; LCSC Part C82544
F2: MF-MSMF050-2; FUSC4632X85N; Mouser Part Number 652-MF-MSMF050-2
H1, H2, H3, H4: MountingHole; MountingHole_3.2mm_M3
IC1: MCP1703AT-3302E_CB; SOT95P255X145-3N; Mouser Part Number 579-MCP1703AT3302ECB
IC2: STM32F205RET6; QFP50P1200X1200X160-64N; Mouser Part Number 511-STM32F205RET6
J2: FH19C-24S-0.5SH_10_; FH19C24S05SH10; Mouser Part Number 798-FH19C24S05SH10
J6: Conn_ARM_SWD_TagConnect_TC2030; Tag-Connect_TC2030-IDC-FP_2x03_P1.27mm_Vertical
L2: XAL4040-103MEC; IND-SMD_L4.0-W4.0_XAL4040; MPN XAL4040-103MEC; LCSC Part C5144883
R1, R2: 5.1k +-1% 0402; R_0402_1005Metric_Pad0.72x0.64mm_HandSolder; LCSC Part # C852856
R3: 22R +-1% 0603; R_0603_1608Metric_Pad0.98x0.95mm_HandSolder; LCSC Part # C313710
R4: 22R +-1% 0402; R_0402_1005Metric_Pad0.72x0.64mm_HandSolder; LCSC Part # C2686485
R5: 1M +-1% 0603; R_0603_1608Metric_Pad0.98x0.95mm_HandSolder; LCSC Part # C22356470
R7: 12k +-1% 0402; R_0402_1005Metric_Pad0.72x0.64mm_HandSolder; LCSC Part # C2909316
R9: 910k +-1% 0603; R_0603_1608Metric_Pad0.98x0.95mm_HandSolder; LCSC Part # C23263
R10: 191k +-1% 0603; R_0603_1608Metric_Pad0.98x0.95mm_HandSolder; LCSC Part # C2974031
R11: 10k +-1% 0603; R_0603_1608Metric_Pad0.98x0.95mm_HandSolder; LCSC Part # C98220
S1, S3: SKHCBGA010; Mouser Part Number 688-SKHCBGA010
U1: SX1308; SOT-23-6_L2.9-W1.6-P0.95-LS2.8-BL; MPN SX1308; LCSC Part C78162
USB1: USB4215-03-A; USB-C-SMD_GT-USB-7010B; MPN USB4215-03-A; LCSC Part C37616412
Y1: ABMM2-8.000MHZ-E2-T; ABMM2; Mouser Part Number 815-ABMM2-8-E2T

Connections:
+3.3V: C5.2, C7.2, C8.2, C9.2, C10.2, C11.2, C12.2, C16.2, C17.2, IC1.2 (VOUT), IC2.1 (VBAT), IC2.13 (VDDA), IC2.19 (VDD_1), IC2.32 (VDD_2), IC2.48 (VDD_3), IC2.64 (VDD_4), J2.5, J6.1 (VCC)
+5V: C6.2, C20.1, C23.1, F2.1, IC1.3 (VIN), L2.1, U1.4 (EN), U1.5 (VIN)
CS#: IC2.20 (PA4), J2.8
D0 (SCLK): IC2.21 (PA5), J2.13
D1 (MOSI): IC2.23 (PA7), J2.14
D/C#: IC2.26 (PB0), J2.10
GND: C1.1, C2.1, C3.1, C4.2, C5.1, C6.1, C7.1, C8.1, C9.1, C10.1, C11.1, C12.1, C13.1, C14.1, C15.1, C16.1, C17.1, C20.2, C21.2, C22.2, C23.2, D1.1 (ground), IC1.1 (GND), IC2.12 (VSSA), IC2.18 (VSS_1), IC2.60 (BOOT0), IC2.63 (VSS_2), J2.1, J2.2, J2.3, J2.6, J2.7, J2.24, J2.MP1, J2.MP2, J6.5 (GND), R1.1, R2.1, R5.1, R9.1, R11.2, S1.1, S1.2, S3.1, S3.2, U1.2 (GND), USB1.A1B12 (GND), USB1.B1A12 (GND)
IREF: J2.21, R9.2
unnamed: D1.4 (supply_voltage), D2.2 (A), R7.2, USB1.A4B9 (VBUS), USB1.B4A9 (VBUS)
unnamed: D2.1 (K), F2.2
unnamed: D3.2 (A), L2.2, U1.1 (SW)
unnamed: IC2.42 (PA9), R7.1
unnamed: IC2.44 (PA11), R3.1
unnamed: IC2.45 (PA12), R4.1
unnamed: IC2.10 (PC2), S1.3
unnamed: IC2.25 (PC5), S3.4
unnamed: C13.2, IC2.31 (VCAP_1)
unnamed: C14.2, IC2.47 (VCAP_2)
unnamed: R10.2, R11.1, U1.3 (FB)
unnamed: R1.2, USB1.A5 (CC1)
unnamed: R2.2, USB1.B5 (CC2)
unnamed: C3.2, Y1.2 (GND_1)
unnamed: C2.2, Y1.4 (GND_2)
PD0/OSC: IC2.5 (PH0_-OSC_IN), Y1.1 (X1)
PD1/OSC: IC2.6 (PH1-_OSC_OUT), Y1.3 (X2)
RES#: IC2.27 (PB1), J2.9
SH_Left: R5.2, USB1.14 (EH), USB1.16 (EH)
SH_Right: C1.2, USB1.13 (EH), USB1.15 (EH)
SWCLK: IC2.49 (PA14), J6.4 (SWCLK)
SWDIO: IC2.46 (PA13), J6.2 (SWDIO)
SWO: IC2.55 (PB3), J6.6 (SWO)
USB_D+: D1.2 (input/output_1), R4.2, USB1.A6 (Dp1), USB1.B6 (Dp2)
USB_D-: D1.3 (input/output_2), R3.2, USB1.A7 (Dn1), USB1.B7 (Dn2)
VCOMH: C15.2, J2.22
VOP: C21.1, C22.1, D3.1 (K), J2.23, R10.1
nRESET: C4.1, IC2.7 (NRST), J6.3 (~RESET)

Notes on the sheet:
USB Type C
Display FPC 24 pin
910k ≈ 10µA nominal brightness
BS2
VCOMH
Flash Port
This is 2.55 N Force
R/W#
BS1
SKHCBGA010 is 2.55 N
Cancel Button
+12V for Display
VLSS
Confirm Button
Duty cycle: D = 1 − (5V/12V) ≈ 0.58 Ripple current: ΔI = (5V × 0.58) / (10µH × 1.2MHz) ≈ 240mA Average inductor current: ≈ 85mA (your display load) Peak current: 85mA + 120mA ≈ ~210mA
IREF
E/RD#

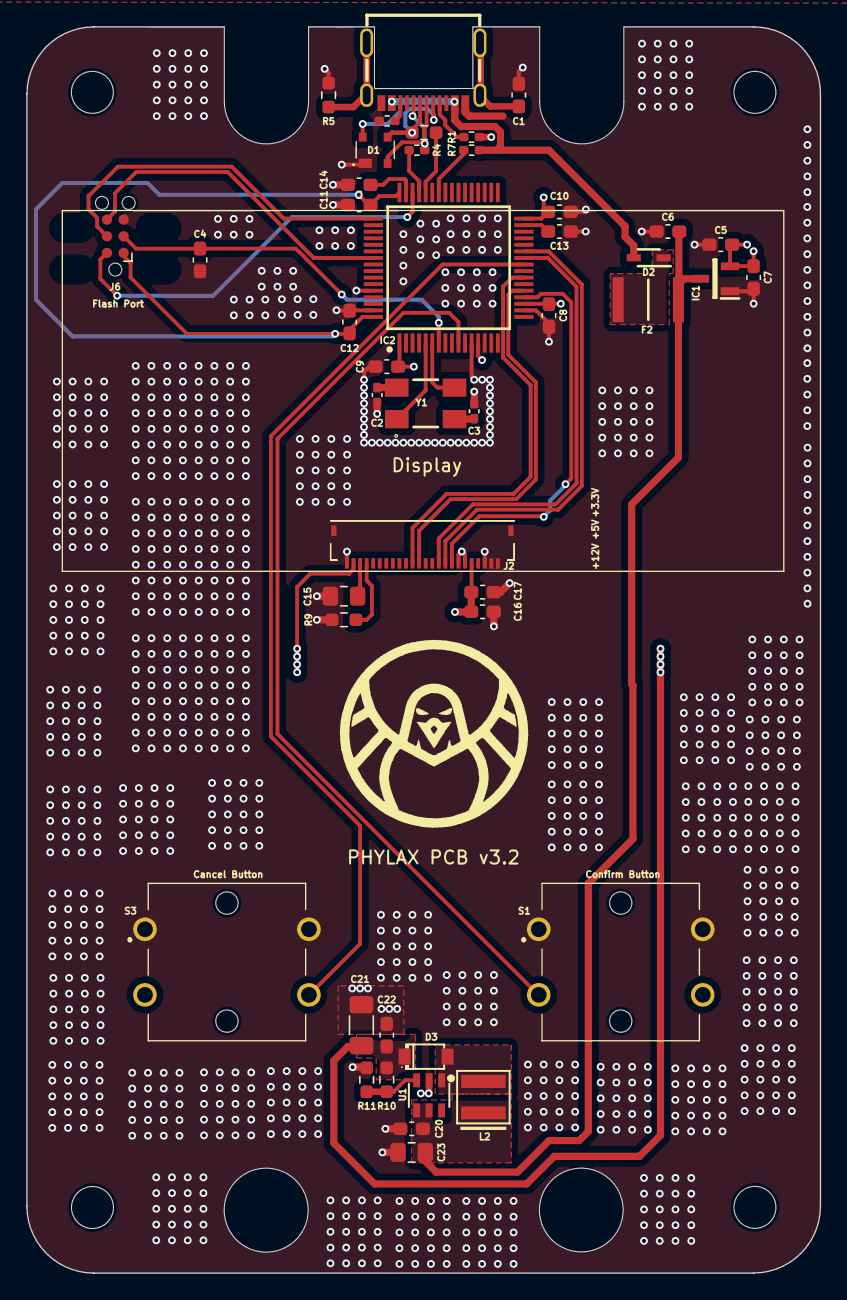
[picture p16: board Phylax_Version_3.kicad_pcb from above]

Board: 2 copper layers, 60.5 x 95.0 mm, 48 parts (0 on the bottom side), 36 nets.

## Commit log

2026-09-15 Initial commit: Phylax Version 3 Square Button
    [Assembly.FCStd, Back Tar Version v3.stl, Back v3-1.stl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]
2026-09-21 Update to version 3.3
    [Assembly.FCStd, Back v3-3.stl, Display Lock v3-2.stl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]
2026-09-21 Update Button to be 2.55 N
    [Phylax_Version_3.kicad_pcb, Phylax_Version_3.kicad_sch, bom.csv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]
2026-09-21 Update JCSC part number
    [Phylax_Version_3.kicad_sch]
2026-09-21 Update JCSC data field to PCB
    [Phylax_Version_3.kicad_pcb, bom.csv]
2026-09-21 Update BOM
    [Phylax_Version_3.kicad_pcb, Phylax_Version_3.kicad_sch, bom.csv]
2026-10-22 Update PCB design, component libraries, and production outputs
2026-10-22 Update board layout, 3D model, and production files
